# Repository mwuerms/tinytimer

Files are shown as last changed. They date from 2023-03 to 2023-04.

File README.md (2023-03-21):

# tinytimer

TinyTimer is a small electronic device (using Attiny404) on a pcb, which offers 4 simple timers and each a led to gently inform the user of an alarm.

## User interface

The led shows the status of the timer
+ off (LED off)
+ running (gently fade in 1 - 2 s)
+ pause (double blink shortly in 1 - 2 s)
+ alarm (blink wildly for 20 s)

With the button, the user can control the timer
+ start
+ pause/resume
+ stop/abort

Each timer has a fixed timeout, eg.
1. 3 min (tea)
2. 5 min
3. 10 min
4. 25 min

Each timer can run independently from all others.

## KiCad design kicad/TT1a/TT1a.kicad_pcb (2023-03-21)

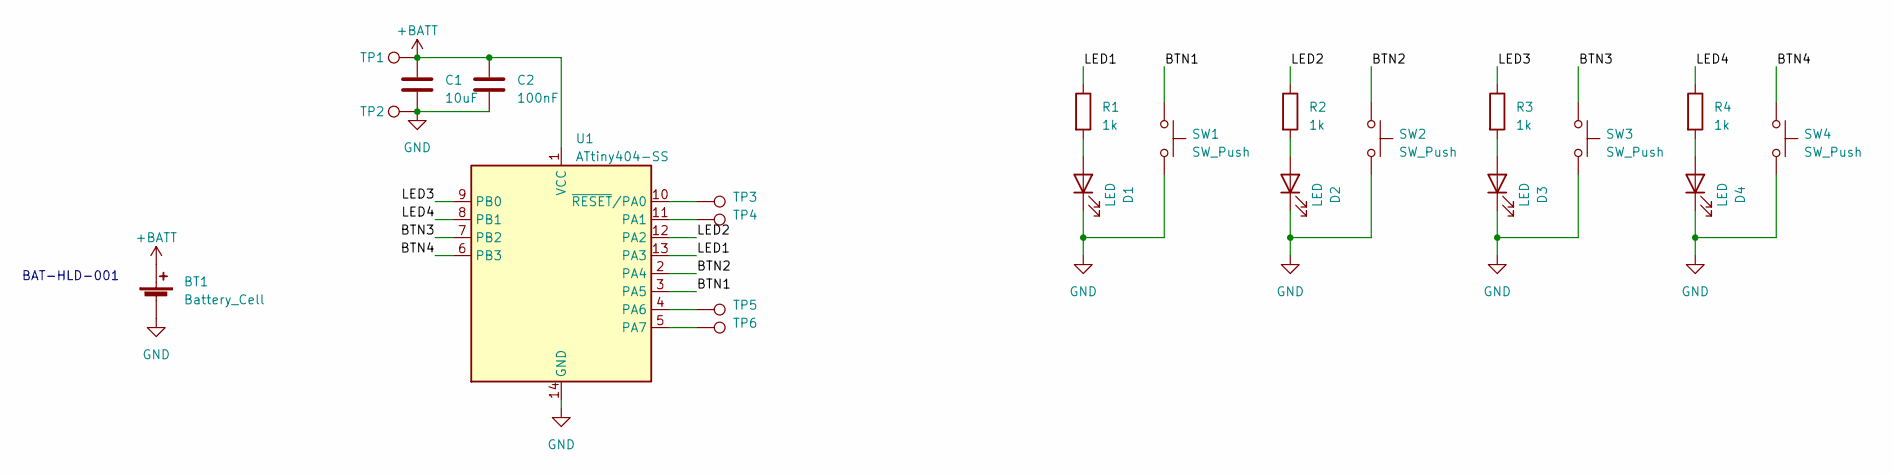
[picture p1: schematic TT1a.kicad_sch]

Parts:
BT1: Battery_Cell; BAT-HLD-001
C1: 10uF; C_0805_2012Metric
C2: 100nF; C_0603_1608Metric
D1, D2, D3, D4: LED; LED_0603_1608Metric
R1, R2, R3, R4: 1k; R_0603_1608Metric
SW1, SW2, SW3, SW4: SW_Push; PTS526_button
TP1, TP2, TP3, TP4, TP5, TP6: TestPoint; TestPoint_Pad_D1.0mm
U1: ATtiny404-SS; SOIC-14_3.9x8.7mm_P1.27mm

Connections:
+BATT: BT1.1 (+), C1.1, C2.1, TP1.1, U1.1 (VCC)
/BTN1: SW1.1, U1.3 (PA5)
/BTN2: SW2.1, U1.2 (PA4)
/BTN3: SW3.1, U1.7 (PB2)
/BTN4: SW4.1, U1.6 (PB3)
/LED1: R1.1, U1.13 (PA3)
/LED2: R2.1, U1.12 (PA2)
/LED3: R3.1, U1.9 (PB0)
/LED4: R4.1, U1.8 (PB1)
GND: BT1.2 (-), C1.2, C2.2, D1.1 (K), D2.1 (K), D3.1 (K), D4.1 (K), SW1.2, SW2.2, SW3.2, SW4.2, TP2.1, U1.14 (GND)
unnamed: D1.2 (A), R1.2
unnamed: D2.2 (A), R2.2
unnamed: D3.2 (A), R3.2
unnamed: D4.2 (A), R4.2
unnamed: TP4.1, U1.11 (PA1)
unnamed: TP5.1, U1.4 (PA6)
unnamed: TP6.1, U1.5 (PA7)
unnamed: TP3.1, U1.10 (~RESET/PA0)

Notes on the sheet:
BAT-HLD-001

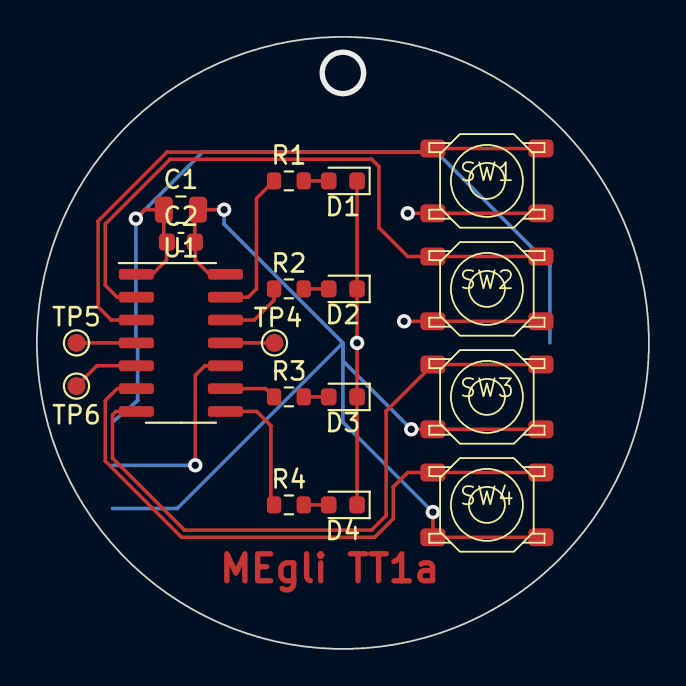
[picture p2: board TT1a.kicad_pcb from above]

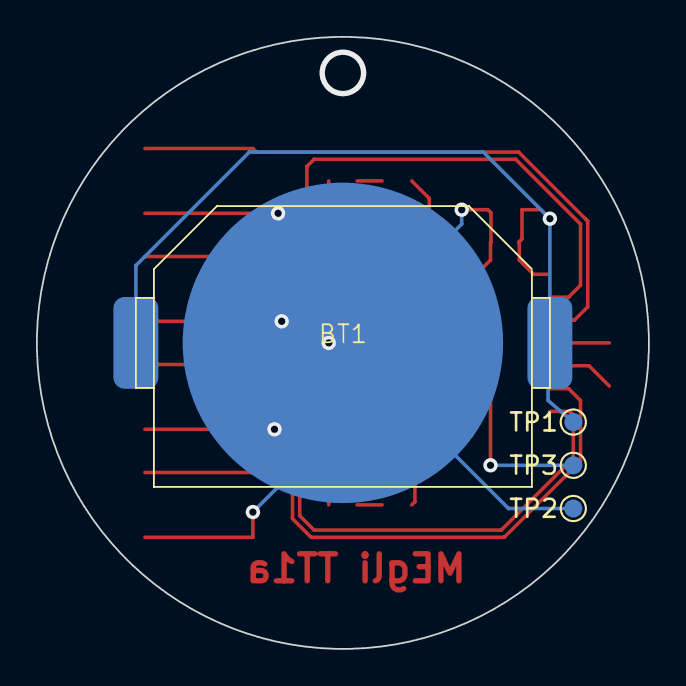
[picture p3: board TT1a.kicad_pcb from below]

Board: 2 copper layers, 34.0 x 34.0 mm, 22 parts (4 on the bottom side), 18 nets.

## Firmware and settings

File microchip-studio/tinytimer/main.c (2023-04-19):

/**
 * Martin Egli
 * 2023-03-21
 * main loop
 */

// in io.h #include <avr/io.h>
#include <avr/interrupt.h>
#include <avr/cpufunc.h>

#include "project.h"
#include "leds.h"
#include "buttons.h"
#include "pwr.h"
#include "rtc.h"
#include "ttimer.h"
#include "dbguart.h"

volatile uint8_t global_events;

void clock_init(void) {
	CCP = CCP_IOREG_gc;     //unlock
	CLKCTRL.MCLKCTRLA = CLKCTRL_CLKSEL_OSC20M_gc; // 20 MHz
	CLKCTRL.MCLKCTRLB = 0;  //no prescale, PEN = 0 -> no prescaler
	// no lock CLKCTRL.MCLKLOCK = 0; // no lock
	// no RUNSTANDY CLKCTRL.OSC20MCTRLA = 0;
}

void cpuint_Init(void) {
	//	FUSE.OSCCFG = FUSE_FREQSEL0_bm
	//SIGROW.DEVICEID0

}

int main(void)
{
	uint8_t local_events = 0;
	global_events = 0;

	clock_init();
	cpuint_Init();
	dbguart_Init();
	dbguart_SendString("hello from tinyTimer\n initialize ");

	leds_Init();
	dbguart_SendChar('.');
	pwr_Init();
	dbguart_SendChar('.');
	pwr_UseMode(PWR_POWER_DOWN);
	dbguart_SendChar('.');
		
	leds_Init();
	dbguart_SendChar('.');
	buttons_Init();
	dbguart_SendChar('.');
	rtc_Init();
	dbguart_SendChar('.');
	rtc_StartModule();
	dbguart_SendChar('.');
	ttimer_Init();
	dbguart_SendChar('.');

	dbguart_SendString(" done\n");

	sei();

	/* testing
	leds_ShowRunning(BUTTON1);
	//leds_ShowPause(BUTTON1);
	//ttimer_ProcessEvents(BUTTON1, TT_EV_BUTTON_1s_LONG_PRESSED);
	ttimer_ProcessEvents(BUTTON2, TT_EV_BUTTON_1s_LONG_PRESSED);
	ttimer_ProcessEvents(BUTTON3, TT_EV_BUTTON_1s_LONG_PRESSED);
	ttimer_ProcessEvents(BUTTON4, TT_EV_BUTTON_1s_LONG_PRESSED);
	*/
    while (1) 
    {
		if(local_events & EV_BUTTON) {
			button_ProcessEvent();
		}

		if(local_events & EV_RTC) {
			rtc_ProcessEvent();
		}

		// synv events from background and/or go to sleep
		while(1) {
			cli();
			// sync from background
			local_events = global_events;
			global_events = 0;
			
			if(local_events) {
				sei();
				break;
			}
			pwr_Sleep();
		}
    }
}

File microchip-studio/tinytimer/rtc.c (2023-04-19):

/**
 * Martin Egli
 * 2023-03-21
 * module tiny timer
 */

#include <util/atomic.h>
#include <avr/io.h>
#include <avr/cpufunc.h>
#include <avr/interrupt.h>
#include "project.h"
#include "io.h"
#include "rtc.h"
#include "ttimer.h"
#include "pwr.h"
#include "leds.h"
#include "dbguart.h"

typedef enum {
    RTC_ST_OFF = 0,
    RTC_ST_RUNNING,
    RTC_ST_PAUSE,
    RTC_ST_TIMEOUT
} rtc_state_t;

typedef union {
    uint32_t u32;
    struct {
        uint16_t l;
        uint16_t h;
    } u16;
} uint16_32_t;

static uint16_32_t rtc_systime; // in 1/1024 seconds
static inline void rtc_UpdateSystime(void) {
    ATOMIC_BLOCK(ATOMIC_RESTORESTATE) {
        rtc_systime.u16.l = rtc_GetCNT();
    }
}

typedef struct {
    uint16_32_t starttime; // in 1/1024 seconds
    uint16_32_t duration; // in 1/1024 seconds
    uint16_32_t compare; // in 1/1024 seconds
    uint16_t timeout_s;
    uint8_t status;     // use rtc_state_t
} rtc_timer_t;

static rtc_timer_t rtc_timers[NB_RTC_TIMER];
static volatile uint8_t rtc_timer_process_list[NB_RTC_TIMER+2]; // store timer_nb to reference in rtc_timers
#define RTC_PROCESS_TIMER_LIST_SIZE (sizeof(rtc_timer_process_list)/sizeof(rtc_timer_process_list[0]))
#define RTC_PROCESS_TIMER_UNUSED 0xFF

static inline void rtc_ManageCMP(void);

static inline void rtc_UpdateDurationOfRTCTimer(uint8_t timer_nb, uint32_t now) {
    rtc_timers[timer_nb].starttime.u32 = rtc_systime.u32;   // now
    rtc_timers[timer_nb].duration.u32 = rtc_timers[timer_nb].compare.u32 - rtc_timers[timer_nb].starttime.u32;  // duration = time left = end - now
}

// insert timer_nb at rtc_timer_process_list[pos]
// copy all elements from pos 1 up
// ignore RTC_PROCESS_TIMER_UNUSED for purpose of simplicity
static void rtc_InsertTimerInTimerProcessListAtPosition(uint8_t timer_nb, uint8_t pos) {
    uint8_t n, temp;
    for(n = pos; n < RTC_PROCESS_TIMER_LIST_SIZE; n++) {
        temp = rtc_timer_process_list[n];
        rtc_timer_process_list[n] = timer_nb;
        timer_nb = temp;
    }
}

// sort in by calculated duration?, smallest/next at the front
static uint8_t rtc_SortTimerInTimerProcessListByDuration(uint8_t timer_nb) {
    uint8_t n;
    rtc_UpdateSystime();
    // check if there is any space left in rtc_timer_process_list
    // update duration in rtc_timer_process_list
    for(n = 0; n < RTC_PROCESS_TIMER_LIST_SIZE; n++) {
        if(rtc_timer_process_list[n] == RTC_PROCESS_TIMER_UNUSED) {
            // found end of list
            break;
        }
        rtc_UpdateDurationOfRTCTimer(rtc_timer_process_list[n], rtc_systime.u32);
    }
    // sort new timer in by its duration.u32
    for(n = 0; n < RTC_PROCESS_TIMER_LIST_SIZE; n++) {
        if(rtc_timer_process_list[n] == RTC_PROCESS_TIMER_UNUSED) {
            // this place in unused, use this one
            rtc_timer_process_list[n] = timer_nb;
            // done
            break;
        }
        if(rtc_timers[timer_nb].duration.u32 < rtc_timers[rtc_timer_process_list[n]].duration.u32) {
            // insert timer_nb at this point
            rtc_InsertTimerInTimerProcessListAtPosition(timer_nb, n);
            // done
            break;
        }
    }
    rtc_UpdateSystime();
    rtc_ManageCMP();
    return 0;
}

#define rtc_PeekTimerProcessList() rtc_timer_process_list[0];

static uint8_t rtc_RemovePosFromTimerProcessList(uint8_t pos) {
    uint8_t ans, n;
    ans = rtc_timer_process_list[pos];
    for(n = pos; n < (RTC_PROCESS_TIMER_LIST_SIZE-1); n++) {
        rtc_timer_process_list[n] = rtc_timer_process_list[n+1];
    }
    rtc_timer_process_list[n] = RTC_PROCESS_TIMER_UNUSED;
    return ans;
}

// pop 1st, copy all others from back ot front, [0] = front/head, fill in UNUSED at the back
static uint8_t rtc_RemoveHeadFromTimerProcessList(void) {
    return rtc_RemovePosFromTimerProcessList(0);
}

static uint8_t rtc_RemoveGivenTimerNbFromTimerProcessList(uint8_t timer_nb) {
    uint8_t n, pos;
    // find pos of timer_nb
    pos = RTC_PROCESS_TIMER_LIST_SIZE;
    for(n = 0; n < RTC_PROCESS_TIMER_LIST_SIZE; n++) {
        if(rtc_timer_process_list[n] == timer_nb) {
            // found, save in pos
            pos = n;
        }
    }
    if(pos == RTC_PROCESS_TIMER_LIST_SIZE) {
        // not found, so do not remove
        return RTC_PROCESS_TIMER_UNUSED;
    }
    return rtc_RemovePosFromTimerProcessList(pos);
}

static inline void rtc_InitTimerProcessList(void) {
    uint8_t n;
    for(n = 0; n < RTC_PROCESS_TIMER_LIST_SIZE; n++) {
        rtc_timer_process_list[n] = RTC_PROCESS_TIMER_UNUSED;
    }
}

static void rtc_SendLEDEvent(void) {
    uint8_t proc_timer = rtc_RemoveHeadFromTimerProcessList();
    if(proc_timer != RTC_PROCESS_TIMER_UNUSED) {
        if(rtc_timers[proc_timer].status == RTC_ST_RUNNING) {
            rtc_timers[proc_timer].status = RTC_ST_TIMEOUT;
            global_events |= EV_RTC;
        }
    }
}

#if DBG_UART()
static inline void rtc_PrintTimerProcessList(void) {
    uint8_t n, proc_timer;
    ATOMIC_BLOCK(ATOMIC_RESTORESTATE) {
        dbguart_SendString("_PTL");
        for(n = 0; n < RTC_PROCESS_TIMER_LIST_SIZE; n ++) {
            proc_timer = rtc_timer_process_list[n];
            dbguart_SendChar('[');
            dbguart_SendChar(n);
            dbguart_SendChar(']');
            dbguart_SendChar(proc_timer);
            dbguart_SendChar(',');
            dbguart_SendChar(rtc_timers[proc_timer].status);
        }
    }
}
#else
#define rtc_PrintTimerProcessList(...)
#endif

static inline void rtc_ManageCMP(void) {
    ATOMIC_BLOCK(ATOMIC_RESTORESTATE) {
        rtc_PrintTimerProcessList();
        uint8_t proc_timer = rtc_PeekTimerProcessList();
        if(proc_timer != RTC_PROCESS_TIMER_UNUSED) {
            if(rtc_timers[proc_timer].status == RTC_ST_RUNNING) {
                if(rtc_timers[proc_timer].compare.u16.h == rtc_systime.u16.h) {
                    // set CMP to u16.l
                    if(rtc_timers[proc_timer].compare.u16.l > 5) {
                        RTC.CMP = rtc_timers[proc_timer].compare.u16.l;
                        RTC.INTFLAGS = RTC_CMP_bm;  // clr
                        RTC.INTCTRL |= RTC_CMP_bm;  // enable CMP
                    }
                    else {
                        // do call rtc_SendLEDEvent() from here, because sync will not work on only 5 RTC_CNTs
                        rtc_SendLEDEvent();
                        // check next CMP right away here
                        rtc_ManageCMP();
                    }
                }
                else {
                    RTC.INTCTRL &= ~RTC_CMP_bm; // disable CMP
                }
            }
        }
    }
}
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

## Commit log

2023-03-18 started pcb TT1a
    [TT1a.kicad_pcb, TT1a.kicad_sch]
2023-03-18 Schematic done but components arent done yet Bat1: use BAT-HLD-001 Switches: use PTS526 SK15 SMTR2 LFS update library for that
    [TT1a.kicad_pcb, TT1a.kicad_sch]
2023-03-19 TT1a: changed footprints for Bat + Buttons
    [TT1a.kicad_pcb, TT1a.kicad_sch]
2023-03-19 pcb TT1a done
    [TT1a.kicad_pcb, TT1a.kicad_sch]
2023-03-21 README: added short description + user interface
    [TT1a.kicad_pcb]
2023-03-22 tinytimer added rtc, leds, pwr added led animation
2023-03-25 leds: tested leds_ShowRunning() and leds_ShowAlarm() successfully
2023-03-25 leds: variables renamed docs: some calculations added
    [TB0meas.ods]
2023-03-26 rtc: add rtc_timer_process_list to handle all the different timers in one rtc done for the moment, needs some serious testing though
2023-03-26 button started with ISR
2023-03-27 button: 1st version done, may work but this way is not at all prefered
2023-03-27 button: much better now: emit event when ISR gets called and save button state there, then call button_ProcessEvent() from foreground
2023-04-01 leds: added pause smoother "running" animation (better sinus, not so bright, 0 at the end) and more testing
    [TB0meas.ods]
2023-04-12 uart, dbguart: added uart txd functionality for debug purpose (untested)
2023-04-14 uart worked, but wont now :-(
2023-04-19 found "bug" (may be not, rather missunderstanding) in uart, send any character after Init, so the while-loop for status wont dead-lock
    [buttons.c, uart.c]
2023-04-19 works basically, but with some strange behaviour on button3 and when no led is running
